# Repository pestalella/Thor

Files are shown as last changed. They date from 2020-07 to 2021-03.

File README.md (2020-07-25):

# Thor

## A regulated dual-channel linear power supply

* 2 output channels, up to 30V and 3A each
* Possibility to link the 2 channels in series or in parallel
* User input through buttons and a rotary encoder
* TFT display to show the voltage and current limits and the actual outputs
* Possibility to enable or disable the outputs independently

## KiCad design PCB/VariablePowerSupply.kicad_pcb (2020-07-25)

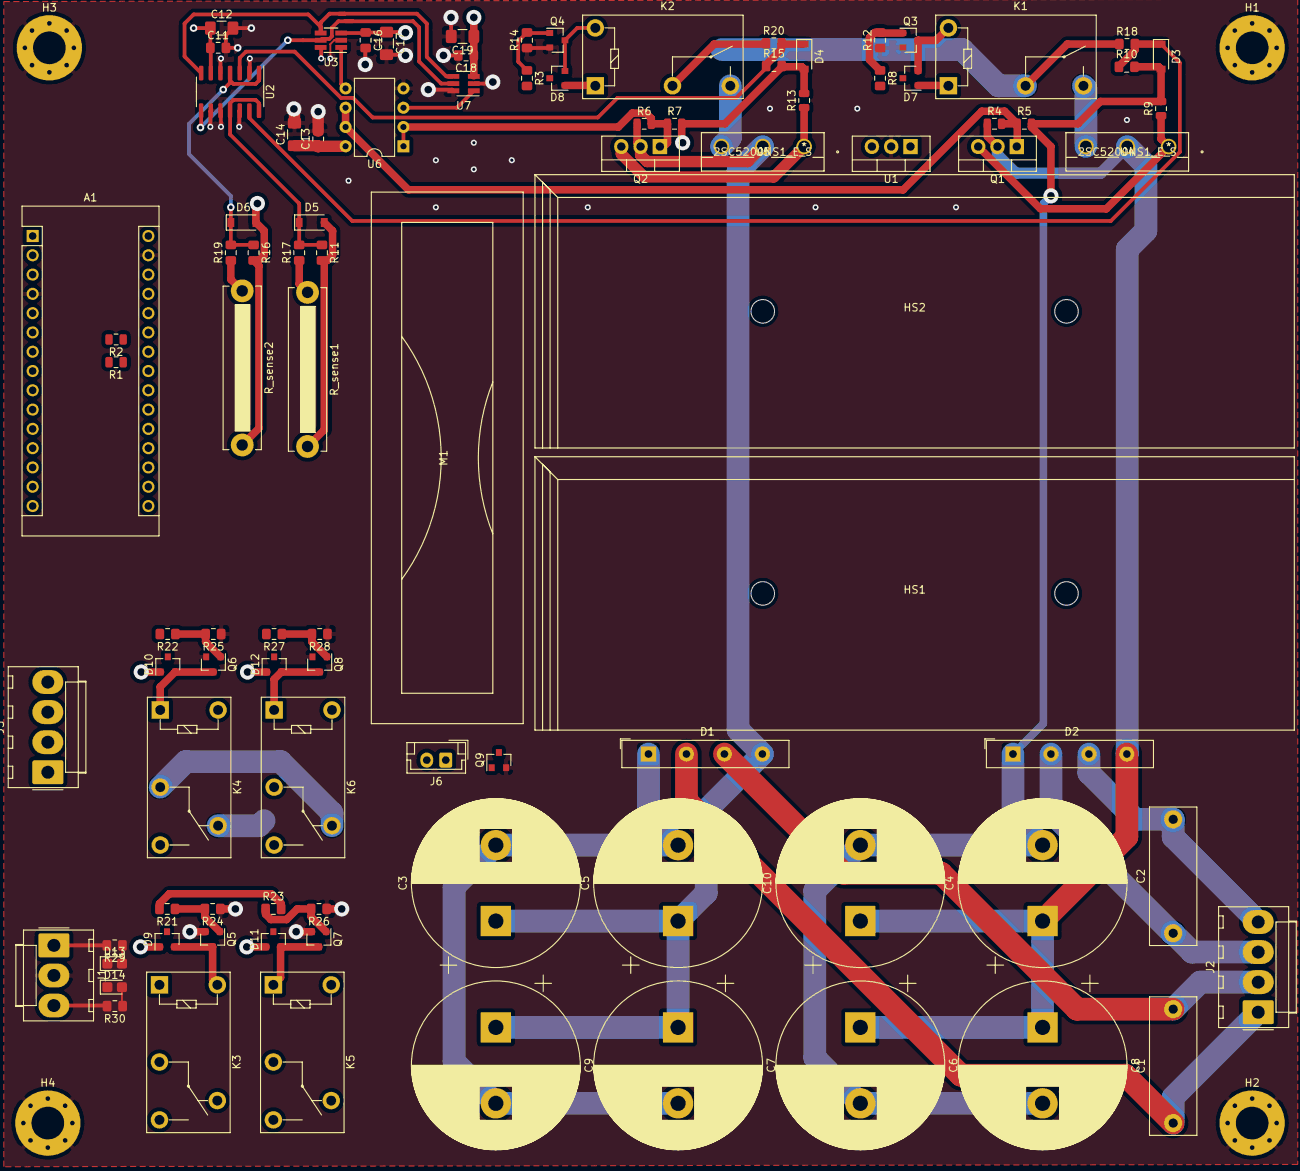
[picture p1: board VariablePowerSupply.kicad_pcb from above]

Board: 4 copper layers, 98 parts (0 on the bottom side), 55 nets.

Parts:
A1: Arduino_Nano_v2.x; Arduino_Nano
C1, C2: C; C_Rect_L18.0mm_W6.0mm_P15.00mm_FKS3_FKP3
C3, C4, C5, C6, C7, C8, C9, C10: C; CP_Radial_D22.0mm_P10.00mm_SnapIn
C11, C13, C16, C18: 0.1uF; C_0805_2012Metric_Pad1.15x1.40mm_HandSolder
C12, C14, C17, C19: 10uF; C_1206_3216Metric_Pad1.42x1.75mm_HandSolder
D1, D2: D_Bridge_-AA+; Diode_Bridge_22.3x3.5x18.3mm_P5.0mm
D3, D4, D5, D6: 5V1; D_SOD-123
D7, D8, D9, D10, D11, D12: D; SOT-23
D13, D14: LED; LED_0805_2012Metric_Castellated
H1, H2, H3, H4: MountingHole_Pad; MountingHole_4.3mm_M4_Pad_Via
HS1, HS2: Heatsink; Heatsink_100x36mm_2xfixations_HorizAirflow
J1: Conn_01x03_Power_Male; Molex_KK-396_A-41791-0003_1x03_P3.96mm_Vertical
J2, J3: Conn_01x04_Male; Molex_KK-396_A-41791-0004_1x04_P3.96mm_Vertical
J6: Conn_01x02_Male; JST_EH_B2B-EH-A_1x02_P2.50mm_Vertical
K1, K2: Relay_SPST_Panasonic_ALQ305
K3, K4, K5, K6: Relay_SPDT_Panasonic_ALQ105; Relay_SPDT_Panasonic-ALQ105
M1: Fan; Fan_Orion_OD7020_vertical
Q1, Q2: TIP41C; TO-220-3_Vertical
Q3, Q4, Q5, Q6, Q7, Q8: 2N7002E; SOT-23
Q9: TSM2302CX; SOT-23
R1, R2: 4k7; R_0805_2012Metric
R3, R8, R10, R11, R15, R16, R21, R22, R23, R27, R30: 1k; R_0805_2012Metric_Pad1.15x1.40mm_HandSolder
R4, R6: 24k; R_0805_2012Metric
R5, R7: 51k; R_0805_2012Metric
R9, R13: 1k; R_0805_2012Metric
R12, R14, R24, R25, R26, R28: 10k; R_0805_2012Metric_Pad1.15x1.40mm_HandSolder
R17, R18, R19, R20: 9k; R_0805_2012Metric_Pad1.15x1.40mm_HandSolder
R29: 220; R_0805_2012Metric_Pad1.15x1.40mm_HandSolder
R_sense1, R_sense2: 0R1; R_Bare_Metal_Element_L21.3mm_W4.8mm_P20.30mm
U1: LM35-NEB; TO-220-3_Vertical
U2: MCP3428; SOIC-14_3.9x8.7mm_P1.27mm
U3, U7: MCP4725A0T-E_CH; SOT-23-6_Handsoldering
U4, U5: 2SC5200NS1_E_S
U6: LT1490CN8PBF; DIP-8_W7.62mm

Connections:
+5V: A1.3, A1.28, A1.30, C11.1, C12.1, C16.1, C17.1, C18.1, C19.1, D7.1, D8.1, D9.1, D10.1, D11.1, D12.1, J1.1, K1.2, K2.2, K3.2, K4.1, K5.1, K6.1, R1.2, R2.2, R29.2, U1.1, U2.6, U3.3, U3.6, U7.3
+12V: C13.1, C14.1, J1.3, J6.2, R30.2, U6.8
/PWR_A_OUT: K2.4, U5.3
/PWR_B_INTERNAL: K4.4, K6.3
/PWR_B_OUT: K1.4, U4.3
/PWR_B_RET_INTERNAL: K3.5, K5.5
FanControl: A1.6, Q9.1
GND: A1.4, A1.29, C11.2, C12.2, C13.2, C14.2, C16.2, C17.2, C18.2, C19.2, D13.1, D14.1, H1.1, H2.1, H3.1, H4.1, J1.2, Q3.2, Q4.2, Q5.2, Q6.2, Q7.2, Q8.2, Q9.2, R12.1, R14.1, R24.1, R25.1, R26.1, R28.1, U1.2, U2.2, U2.5, U2.9, U2.10, U2.12, U3.2, U6.4, U7.2, U7.6
I2C_SCL: A1.24, R2.1, U2.8, U3.5, U7.5
I2C_SDA: A1.23, R1.1, U2.7, U3.4, U7.4
unnamed: C1.1, D1.2, J2.1
unnamed: C1.2, D1.3, J2.2
unnamed: C2.1, D2.2, J2.3
unnamed: C2.2, D2.3, J2.4
unnamed: D3.1, R10.1, R18.2, U2.13
unnamed: D4.1, R15.1, R20.2, U2.3
unnamed: D5.1, R11.1, R17.2, U2.11, U2.14
unnamed: D6.1, R16.1, R19.2, U2.1, U2.4
unnamed: D7.2, K1.1, Q3.3
unnamed: D8.2, K2.1, Q4.3
unnamed: D9.2, K3.1, Q5.3
unnamed: D10.2, K4.2, Q6.3
unnamed: D11.2, K5.2, Q7.3
unnamed: D12.2, K6.2, Q8.3
unnamed: D13.2, R29.1
unnamed: D14.2, R30.1
unnamed: J6.1, Q9.3
unnamed: Q1.3, R9.1, U4.1
unnamed: Q2.3, R13.1, U5.1
unnamed: Q3.1, R8.1, R12.2
unnamed: Q4.1, R3.1, R14.2
unnamed: Q5.1, R21.1, R24.2
unnamed: Q6.1, R22.1, R25.2
unnamed: Q7.1, R23.1, R26.2
unnamed: Q8.1, R27.1, R28.2
unnamed: U3.1, U6.5
unnamed: U6.3, U7.1
OuputA_enable: A1.9, R3.2
OuputB_enable: A1.10, R8.2
ParallelOutput: A1.8, R21.2, R22.2, R23.2
SeriesOutput: A1.7, R27.2
VAN: J3.3, K3.3, K6.5
VAP: J3.4, K2.3, K4.5, R20.1
VBN: J3.1, K5.4
VBP: J3.2, K6.4
V_controlA: Q2.1, R6.2, R7.1, U6.1, U6.2
V_controlB: Q1.1, R4.2, R5.1, U6.6, U6.7
V_temp: A1.19, U1.3
VccA: C3.1, C5.1, C7.1, C9.1, D1.4, Q2.2, R6.1, U5.2
VccB: C4.1, C6.1, C8.1, C10.1, D2.4, Q1.2, R4.1, U4.2
VeeA: C3.2, C5.2, C7.2, C9.2, D1.1, D4.2, D6.2, R7.2, R13.2, R15.2, R16.2, R_sense2.2
VeeB: C4.2, C6.2, C8.2, C10.2, D2.1, D3.2, D5.2, R5.2, R9.2, R10.2, R11.2, R_sense1.2
VoutAN: K3.4, R19.1, R_sense2.1
VoutBN: K5.3, R17.1, R_sense1.1
VoutBP: K1.3, K4.3, R18.1

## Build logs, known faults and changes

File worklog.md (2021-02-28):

### List of connections for the STM32

- SPI for the display  (SS, SCK, MISO, MOSI, RST, DC)
- Analog for Temperature (TEMP_A, TEMP_B)
- I2C for DACs, ADCs  (I2C_SDA, I2C_SCL)
- Rotary encoder 
- SWD  (SWDIO, SWCLK)
- Keyboard address output  (S0, S1, S2)
- Keyboard input (KEYB_IN)
- USART (TX,RX)
- Parallel/Series selection  (PARALLEL_OUT, SERIES_OUT)

### Tasks
- [x] Connect the TFT display and do some testing
- [x] Connect the LM35s and check they can be read
- Connect the rotary encoder and add some code to change settings (voltage, current) with it
- Connect an ADC through I2C
- Connect a DAC through I2C
- Implement setting the desired voltage and current limits
    - Will need 2 cursor keys and the rotary encoder
    - Could also move with the rotary encoder, select by pushing the encoder and exit pushing again
- Relays. Connect them and test the conntrol mechanisms.
- Connect the MOSFET control circuitry.
- Connect a transformer, diode bridge and capacitor bank to one of the channels.
-

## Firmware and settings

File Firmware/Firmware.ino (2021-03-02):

#include "display.h"
#include "keyboard.h"

#define TEMP_A         PA1
#define TEMP_B         PA0

Display disp;
Keyboard keyb;

void setup() {
  Serial.begin(115200);
  Serial.println("ILI9488 Test!");

  pinMode(LED_BUILTIN, OUTPUT);
  pinMode(TEMP_A, INPUT);
  pinMode(TEMP_B, INPUT);

  disp.setUp();
  keyb.setUp();
}

int tempDelayCounter = 0;

bool updateTemperature()
{
  tempDelayCounter++;
  if (tempDelayCounter > 500) {
    tempDelayCounter = 0;
    int tempASensorRead = analogRead(TEMP_A);
    int tempBSensorRead = analogRead(TEMP_B);
    disp.updateTemperatures(tempASensorRead*0.312, tempBSensorRead*0.312);
    return true;
  } else
    return false;
}

bool checkKeyboard()
{
  Keyboard::Key activeKey = keyb.pressedKey();
  bool keyPressed = false;
  switch (activeKey) {
    case Keyboard::Key::DisplayMode:
      disp.changeDisplayPage();
      keyPressed = true;
      break;
    default:
      break;
  }
  return keyPressed;
}

void loop() {
  bool tempUpdates = updateTemperature();
  bool keybUpdates = checkKeyboard();
  if (tempUpdates | keybUpdates) {
    disp.paint();
  }
  delay(1);
}

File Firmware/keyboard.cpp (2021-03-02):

#include "keyboard.h"

RotaryEncoder *isrEncoderObject;
bool encoderUpdated;
bool encoderPushed;
long encoderPosition;
int rotaryPinA = PB5;
int rotaryPinB = PB6;
int rotaryPush = PB7;

void checkPosition()
{
  isrEncoderObject->tick(); // just call tick() to check the state.
  encoderUpdated = true;
  encoderPosition = isrEncoderObject->getPosition();
}

void pushButtonClick()
{
    encoderPushed = true;
}

Keyboard::Keyboard() :
    encoder(rotaryPinA, rotaryPinB, RotaryEncoder::LatchMode::TWO03)
{

}


void Keyboard::setUp()
{
    pinMode(rotaryPush, INPUT_PULLUP);

    isrEncoderObject = &encoder;
    encoderUpdated = false;

    attachInterrupt(rotaryPush, pushButtonClick, FALLING);
    attachInterrupt(rotaryPinA, checkPosition, CHANGE);
    attachInterrupt(rotaryPinB, checkPosition, CHANGE);
}

Keyboard::Key Keyboard::pressedKey()
{  
    static int encoderPos = 0;

    // bool curState = (digitalRead(buttonPin) == HIGH);
    Key retKey = Key::None;
    if (encoderPushed) {
        // keypress happened
        retKey = Key::DisplayMode;
        encoderPushed = false;
    }
    // keyState[DisplayMode] = curState;

    if (encoderUpdated && encoderPos != encoderPosition) {
        Serial.print("pos:");
        Serial.print(encoderPosition);
        Serial.print(" dir:");
        Serial.println((int)(encoder.getDirection()));
        encoderPos = encoderPosition;
        encoderUpdated = false;
    }

    return retKey;
}

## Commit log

2020-07-25 Import existing files
    Import Kicad project, with footprints and schematic. Also import
    some initial Arduino test to interact with the different
    components.
    [VariablePowerSupply.sch]
2020-07-25 Add the PCB file
    [VariablePowerSupply.kicad_pcb]
2020-07-27 Multiply opamp output
    The output DAC will only output up to 5V, as it can only be
    powered with up to 5V. This output needs to be multiplied to
    reach 30V to drive the output.
    [VariablePowerSupply.sch]
2020-07-27 Add output capacitors
    How could I forget about those?
    [VariablePowerSupply.sch]
2021-02-26 Add very preliminary version of VPS FW
    Added temperature reading class and a keyboard reading class.
2021-03-02 Add rotary encoder support
    Add initial code to support a rotary encoder.

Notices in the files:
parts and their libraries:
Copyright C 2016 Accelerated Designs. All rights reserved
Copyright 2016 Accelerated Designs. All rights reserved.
